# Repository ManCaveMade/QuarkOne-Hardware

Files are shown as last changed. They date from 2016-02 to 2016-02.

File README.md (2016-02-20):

# QuarkOne - Hardware
Designed by: Mitchell A. Cox (20 Febrary 2016) (ManCave Made)

Copyright: Mitchell A. Cox (mitch [at] enox [dot] co [dot] za)

License: CERN OHL v1.2

The hardware design files for the Quark One. The free version of eagle is sufficient to open, modify and use the Quark One design files. PDFs are provided for convenience.

The board uses two layers for minimum cost. The Atmel XMEGA microcontroller footprint is compatible with any similar device with different flash size, for example.

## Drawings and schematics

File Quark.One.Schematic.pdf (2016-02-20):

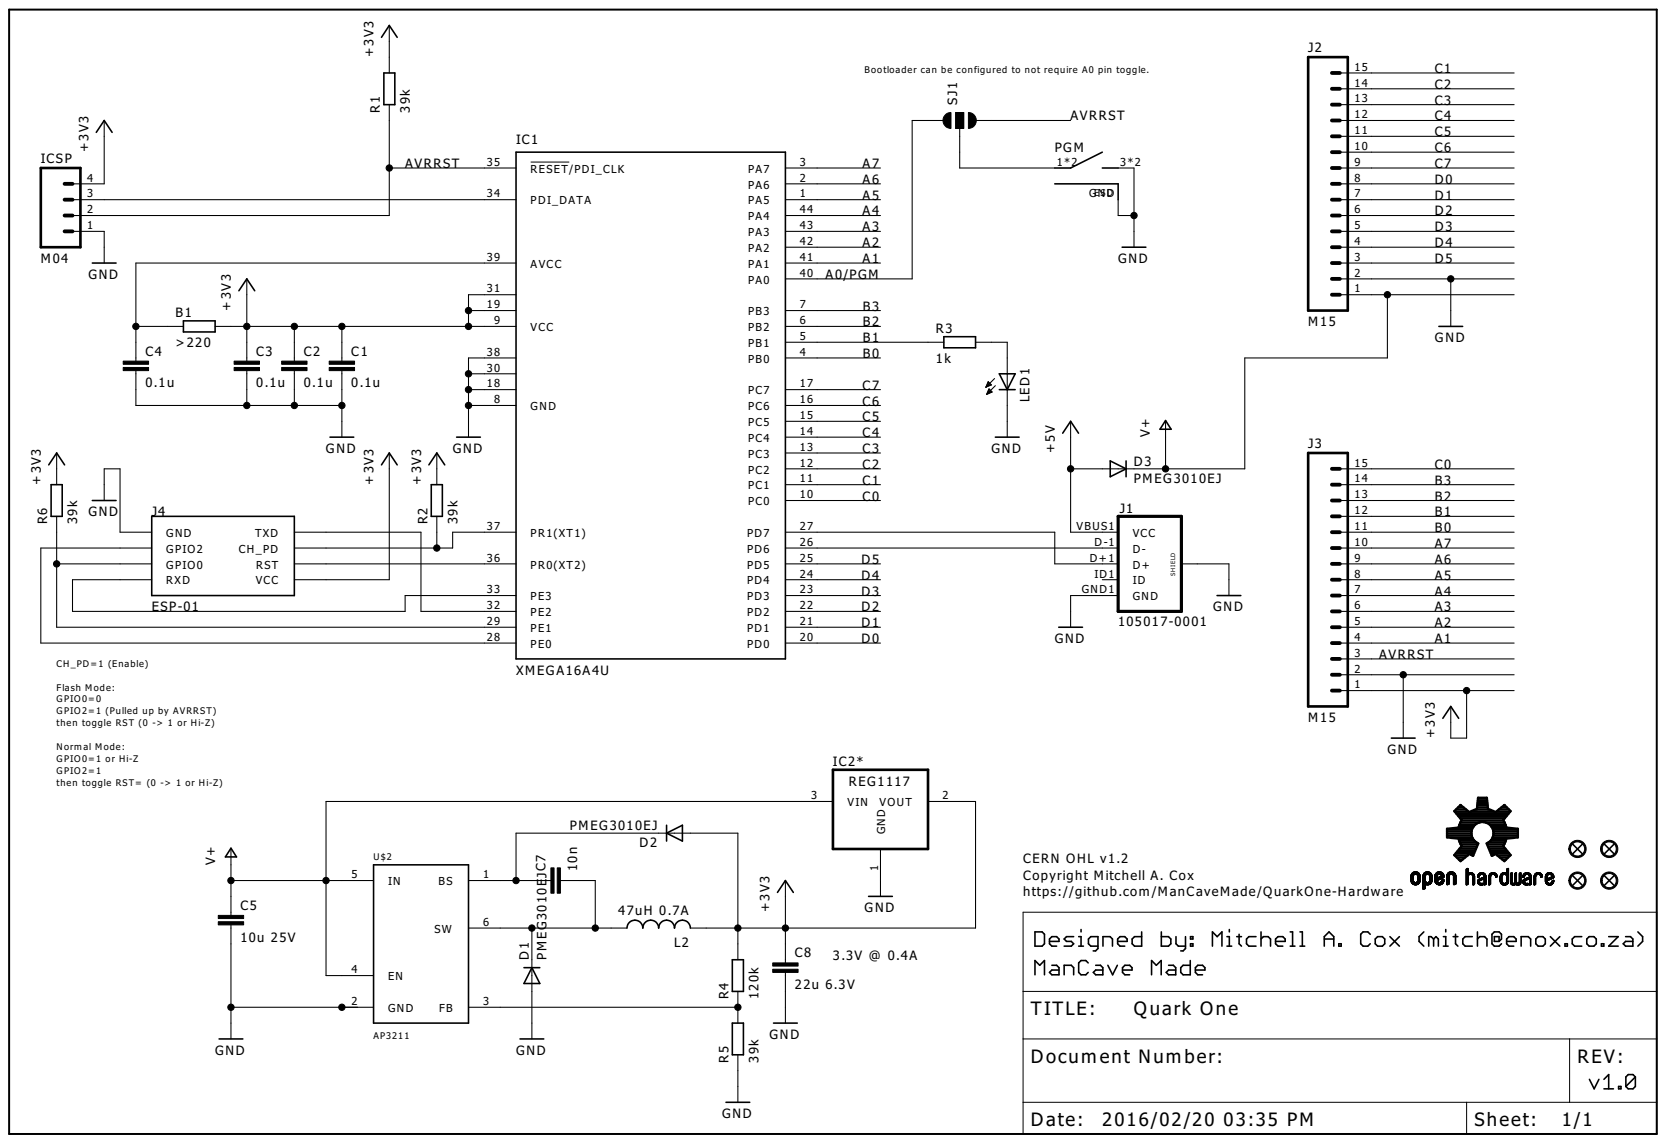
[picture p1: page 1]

Bootloader can be configured to not require A0 pin toggle.

2 | 1 PA4 A4
1 | 44 PA3 A3

CH_PD=1 (Enable) Flash Mode: GPIO0=0 GPIO2=1 (Pulled up by AVRRST)

then toggle RST (0 -> 1 or Hi-Z) Normal Mode: GPIO0=1 or Hi-Z GPIO2=1

then toggle RST= (0 -> 1 or Hi-Z)

CERN OHL v1.2 Copyright Mitchell A. Cox https://github.com/ManCaveMade/QuarkOne-Hardware

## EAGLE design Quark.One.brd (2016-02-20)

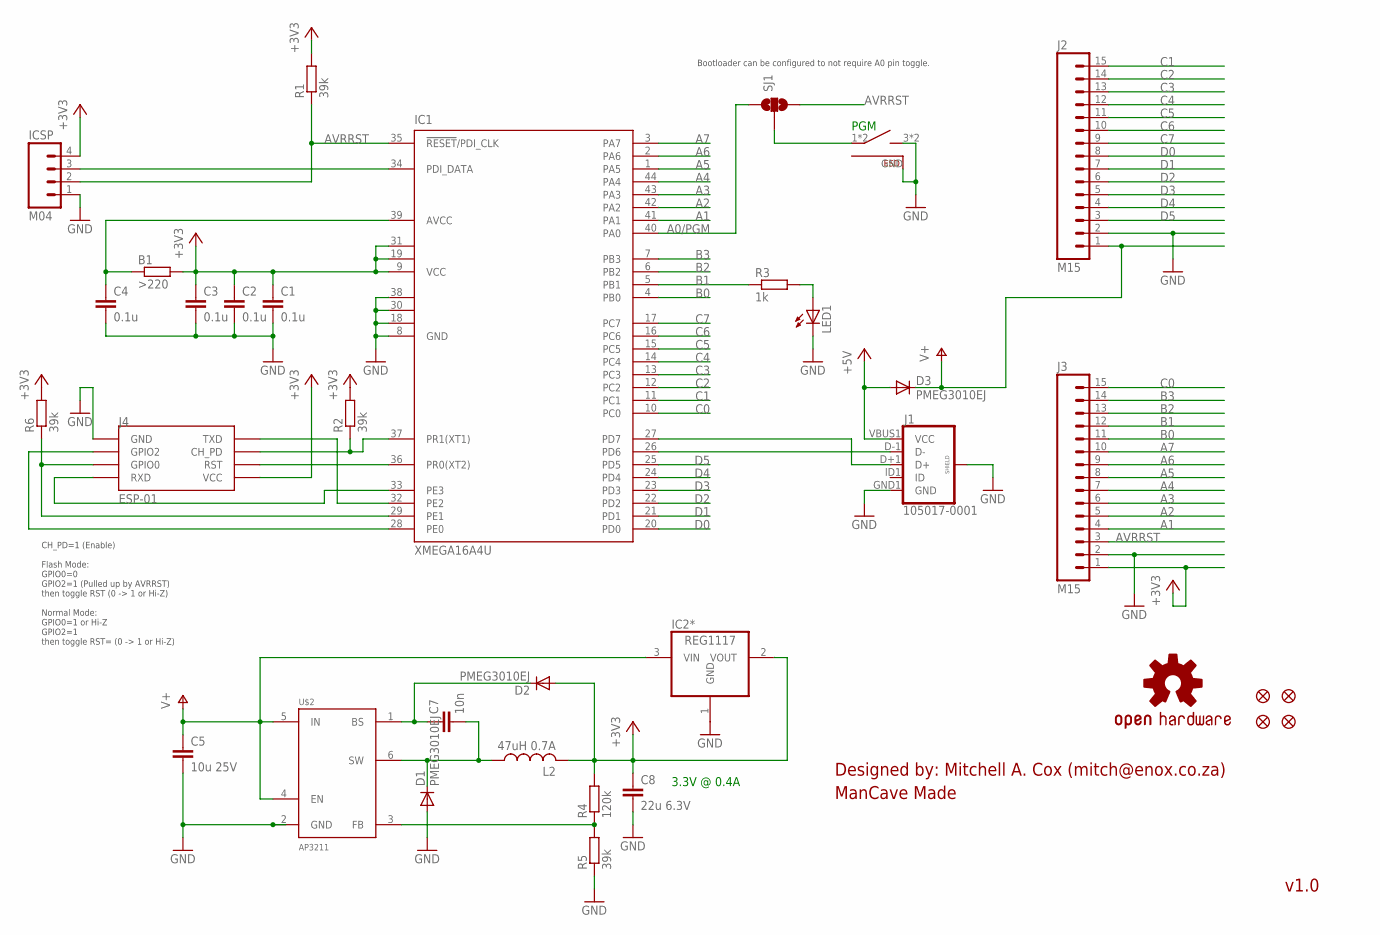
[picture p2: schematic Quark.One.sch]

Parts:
B1: >220; R0603
C1, C2, C3, C4: 0.1u; C0603
C5: 10u 25V; C0805
C7: 10n; C0603
C8: 22u 6.3V; C0805
D1, D2, D3: PMEG3010EJ; SOD-323
IC1: XMEGA16A4U; TQFP44
IC2*: REG1117; SOT223
ICSP: M04; 1X04-LOCK
J1: 105017-0001; USB-MICROB
J2, J3: M15; 1X15
J4: ESP-01; ESP01
JP1, JP2, JP3, JP4: FIDUCIALUFIDUCIAL; MICRO-FIDUCIAL
L2: 47uH 0.7A; LQH44P
LED1: LEDCHIPLED_0603; CHIPLED_0603
R1, R2, R5, R6: 39k; R0603
R3: 1k; R0603
R4: 120k; R0603
S1: PTS840; PTS840-SW
SJ1: SOLDERJUMPER_2WAY-OLDPASTE2&3; SJ_3_PASTE2&3
U$1: OSHW; OSHW-S
U$2: AP3211; SOT23-6

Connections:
+3V3: B1.2, C1.1, C2.1, C3.1, C8.1, D2.2 (A), IC1.9 (VCC), IC1.19 (VCC1), IC1.31 (VCC2), IC2*.2 (VOUT), ICSP.4, J3.1, J4.VCC, L2.2, R1.2, R2.2, R4.2, R6.2
+5V: D3.2 (A), J1.VBUS1 (VCC)
A0/PGM: IC1.40 (PA0), SJ1.1
A1: IC1.41 (PA1), J3.4
A2: IC1.42 (PA2), J3.5
A3: IC1.43 (PA3), J3.6
A4: IC1.44 (PA4), J3.7
A5: IC1.1 (PA5), J3.8
A6: IC1.2 (PA6), J3.9
A7: IC1.3 (PA7), J3.10
AVRRST: IC1.35 (!RESET!/PDI_CLK), ICSP.2, J3.3, R1.1, SJ1.3
B0: IC1.4 (PB0), J3.11
B1: IC1.5 (PB1), J3.12, R3.1
B2: IC1.6 (PB2), J3.13
B3: IC1.7 (PB3), J3.14
C0: IC1.10 (PC0), J3.15
C1: IC1.11 (PC1), J2.15
C2: IC1.12 (PC2), J2.14
C3: IC1.13 (PC3), J2.13
C4: IC1.14 (PC4), J2.12
C5: IC1.15 (PC5), J2.11
C6: IC1.16 (PC6), J2.10
C7: IC1.17 (PC7), J2.9
D0: IC1.20 (PD0), J2.8
D1: IC1.21 (PD1), J2.7
D2: IC1.22 (PD2), J2.6
D3: IC1.23 (PD3), J2.5
D4: IC1.24 (PD4), J2.4
D5: IC1.25 (PD5), J2.3
GND: C1.2, C2.2, C3.2, C4.2, C5.2, C8.2, D1.2 (A), IC1.8 (GND), IC1.18 (GND1), IC1.30 (GND2), IC1.38 (GND3), IC2*.1 (GND), ICSP.1, J1.GND1 (GND), J1.P$1 (SHIELD), J1.P$2 (SHIELD), J1.P$7 (SHIELD), J1.P$8 (SHIELD), J1.SHIELD, J1.SHIELD2 (SHIELD), J2.2, J3.2, J4.GND, LED1.C, R5.1, S1.3, S1.4, S1.GND, U$2.2 (GND)
unnamed: LED1.A, R3.2
unnamed: IC1.32 (PE2), J4.TX (TXD)
unnamed: C7.2, D1.1 (C), L2.1, U$2.6 (SW)
unnamed: IC1.34 (PDI_DATA), ICSP.3
unnamed: B1.1, C4.1, IC1.39 (AVCC)
unnamed: R4.1, R5.2, U$2.3 (FB)
unnamed: IC1.33 (PE3), J4.RX (RXD)
unnamed: IC1.26 (PD6), J1.D-1 (D-)
unnamed: IC1.27 (PD7), J1.D+1 (D+)
unnamed: C7.1, D2.1 (C), U$2.1 (BS)
unnamed: IC1.37 (PR1(XT1)), J4.CH_PD, R2.1
unnamed: IC1.36 (PR0(XT2)), J4.RST
unnamed: IC1.28 (PE0), J4.GPIO2
unnamed: IC1.29 (PE1), J4.GPIO0, R6.1
unnamed: S1.1, S1.2, SJ1.2
V+: C5.1, D3.1 (C), IC2*.3 (VIN), J2.1, U$2.4 (EN), U$2.5 (IN)

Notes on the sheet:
3.3V @ 0.4A
PGM
CH_PD=1 (Enable) Flash Mode: GPIO0=0 GPIO2=1 (Pulled up by AVRRST) then toggle RST (0 -> 1 or Hi-Z) Normal Mode: GPIO0=1 or Hi-Z GPIO2=1 then toggle RST= (0 -> 1 or Hi-Z)
Bootloader can be configured to not require A0 pin toggle.
v1.0
Designed by: Mitchell A. Cox (mitch@enox.co.za) ManCave Made

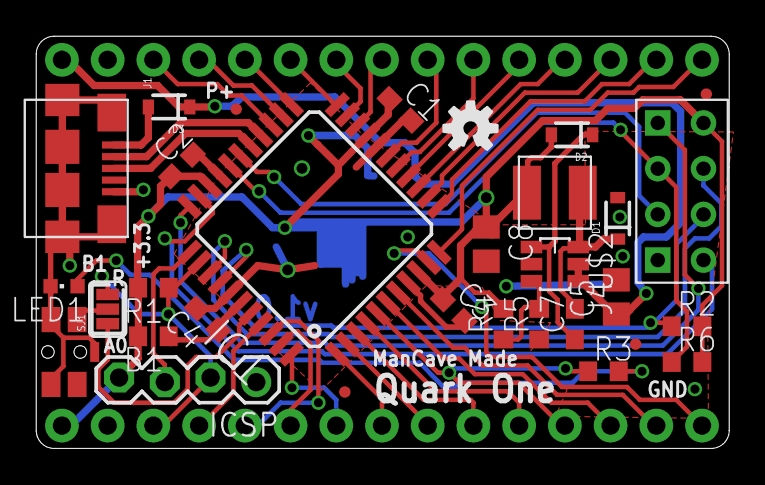
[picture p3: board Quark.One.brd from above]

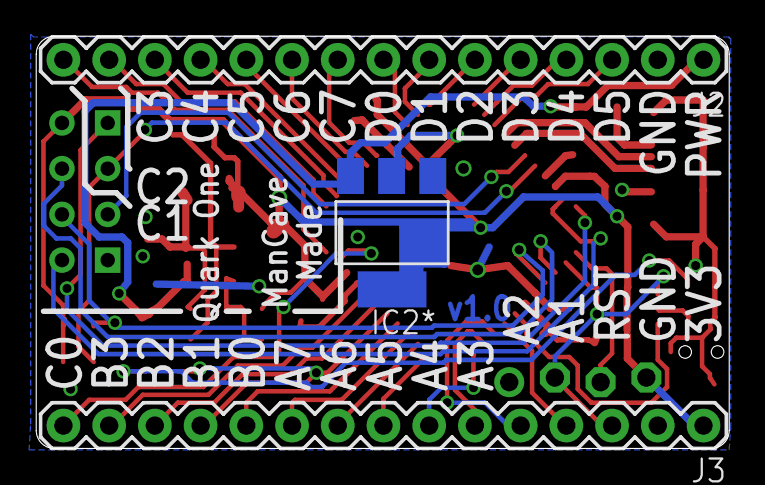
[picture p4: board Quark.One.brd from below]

Board: 2 copper layers, 38.5 x 22.9 mm, 34 parts (3 on the bottom side), 46 nets.

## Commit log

2016-02-20 Added Cadsoft Eagle 7.3.0 design files
    [Quark.One.brd, Quark.One.sch]
2016-02-20 Added schematic PDF

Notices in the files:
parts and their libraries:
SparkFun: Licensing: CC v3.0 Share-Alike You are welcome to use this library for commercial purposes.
